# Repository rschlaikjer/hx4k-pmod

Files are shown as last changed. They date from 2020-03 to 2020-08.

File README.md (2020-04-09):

# HX4k PMOD Breakout

This repository contains the KiCad hardware design files, flash programming
firmware and some gateware samples for a basic FPGA breakout board based on the
Lattice Ice40 HX4K.

More information about this project can be found
[in this blog post](https://rhye.org/post/fpgas-1-running-on-hardware/).

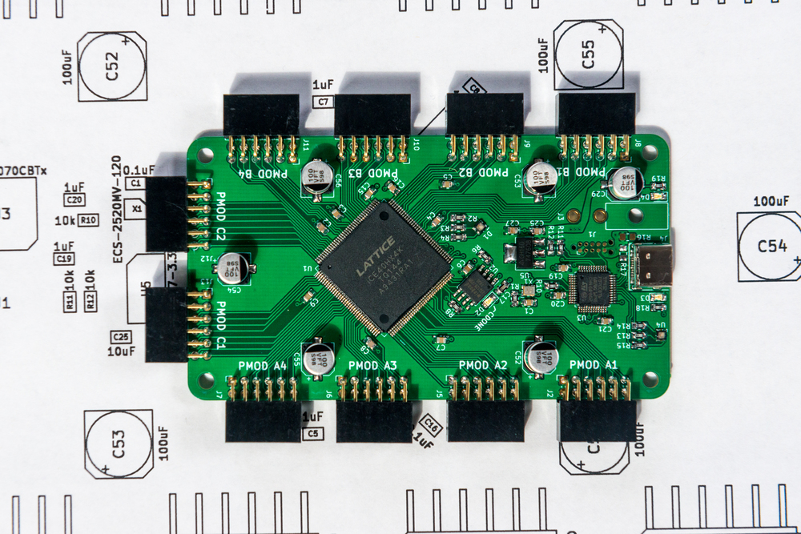
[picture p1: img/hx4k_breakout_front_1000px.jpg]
Assembled Board


## Building the hardware

### Prerequisites

- Soldering iron (TS-100 or TS-80 would be fine for this)
- Flux (Massively simplifies the soldering of the QFP packages)
- Fine tweezers (I recommend [Rhino SW-11](https://www.adafruit.com/product/3096) or comparable)
- [Optional] Hot air rework station. The '858D' hot air station is available
from many resellers at reasonable prices, and is more than adequate.

One of the design goals for this board was for it to be feasible to assemble by
hand, using only a soldering iron. To that end, all of the critical
components are leaded packages, and there are no passives smaller than 0805.
For some components (USB type-C connector J4, 12MHz oscillator X1 and RGB LEDs
D1 and U4), a hot air gun may be advantageous, but it is possible to get away
without one.

### Ordering PCBs

If you have done this before, you can clone this repo and then zip up the
gerber fills in the
[hardware/gerber/](https://github.com/rschlaikjer/hx4k-pmod/tree/master/hardware/gerber/)
directory and upload them to your preferred board house.
Alternately, or for convenience, you can
[order this design directly](https://www.pcbway.com/project/shareproject/Lattice_HX4K_FPGA_Breakout.html)
from PCBWay, a budget PCB house with respectable quality and turnaround time.

### Bill of materials

The KiCad design files are fully specified with the manufacturer and DigiKey
part numbers for all components involved. Also included in the `hardware/` folder
is a DigiKey BOM CSV (`digikey_bom.csv`), which can be uploaded
[here](https://www.digikey.com/BOM/) and used to immediately add the necessary
components to an order. Note that the BOM item quantity is for _precisely_ one
unit - I would recommend going through and adding whatever fudge factor you
feel is reasonable to cheaper passives and other parts you want some margin for
error with.

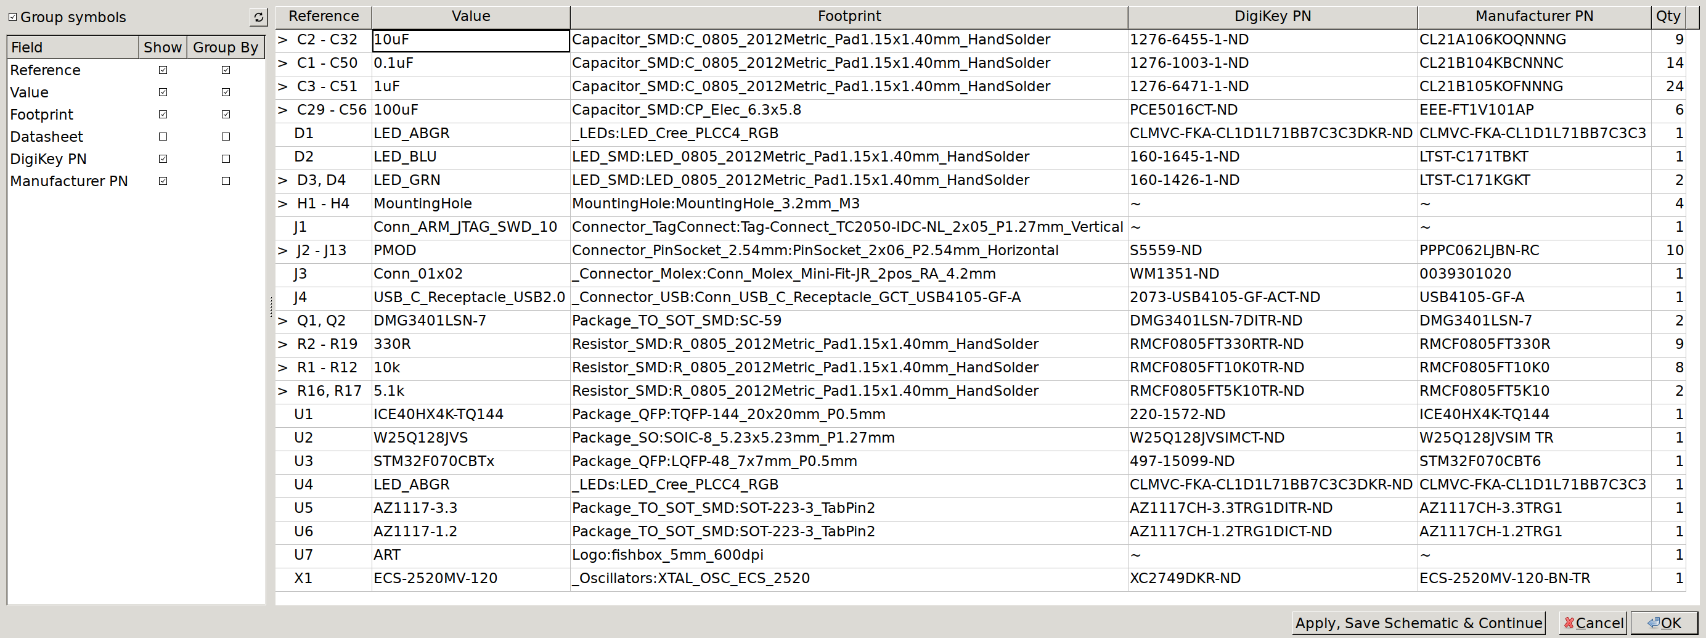
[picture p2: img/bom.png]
BOM View


At time of writing, the total cost of the BOM for no more than one board is $37.60.
If you intend to make more than one, the unit price will of course decrease.

### Assembly

I highly recommend printing out the `F.Fab` and `B.Fab` layers of the KiCad
design before getting to work, as these contain a wireframe layout of all the
components, as well as their associated values (pictured on right hand side). I
would also recommend starting with the center of the major component sections
(U1, U3) and working outwards to smaller components, otherwise some of the
decoupling caps near the chips may make it tricky to solder the QFPs.

If you are using a hot air station for assembly, I would recommend applying
flux to the pads, tinning them, placing the component on top and then using the
hot air tool to reflow it into place. I find 350°C to work well for leaded
solder. Be careful not to overheat the LEDs, as the plastic may melt.

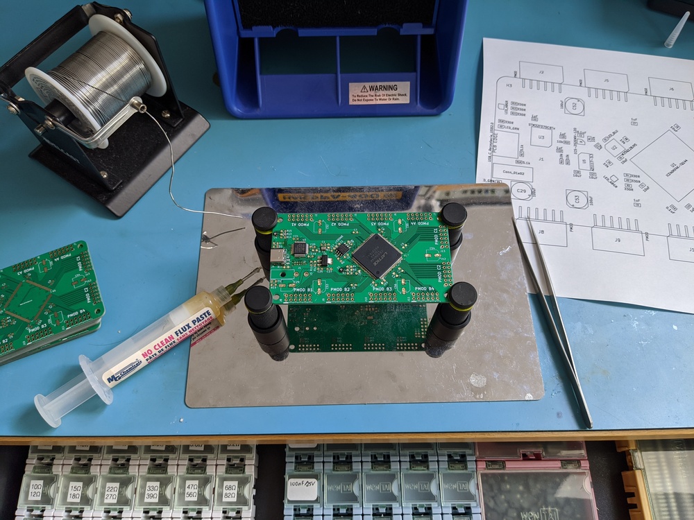
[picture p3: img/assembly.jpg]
Board Assembly


# Flashing the microcontroller

Once you have the hardware assembled, you will need to program the onboard
microcontroller. This micro then acts in much the same way as an FTDI FT2232
(but costs significantly less), and once set up allows for

- Writing bitstreams / other data to the onboard flash chip
- Creating a USB serial bridge to the FPGA
- Any other custom logic you want to add. The microcontroller has one hardware
SPI connected directly to the FPGA for end user applications.

To build the firmware, you will need the `arm-none-eabi` GCC toolchain:

    sudo apt install gcc-arm-none-eabi gdb-arm-none-eabi binutils-arm-none-eabi

You should then be able to build the firmware as a normal CMake project:

    # Ensure submodule for libopencm3 is present
    git submodule init
    git submodule update
    # Build
    mkdir programmer_firmware/build
    pushd programmer_firmware/build
    cmake ../
    make -j$(nproc)

To program, it is assumed that you will be using the
[Black Magic Probe](https://1bitsquared.com/products/black-magic-probe)
with a
[TagConnect TC-2050-NL](https://www.tag-connect.com/product/tc2050-idc-nl-050-all)
cable to connect to the programming pads on the board. In this case, after
connecting power to the board through either the USB connector or auxiliary
power connector,  you can
run the cmake target `fpga_programmer_flash` to attach to the microcontroller
and load the firmware. You should see output like the following:

    ross@mjolnir:/h/r/P/G/f/p/build$ make fpga_programmer_flash
    [ 44%] Built target libopencm3
    [100%] Built target fpga_programmer_elf
    Black Magic Probe (Firmware v1.6.1-311-gfbf1963) (Hardware Version 3)

    Available Targets:
    No. Att Driver
     1      STM32F07 M0
    event_loop () at /home/ross/Programming/Github/fpga-swe-1/programmer_firmware/src/main.cpp:87
    87	}
    Loading section .text, size 0x29e4 lma 0x8000000
    Loading section .init_array, size 0x8 lma 0x80029e4
    Loading section .data, size 0x14 lma 0x80029ec
    Start address 0x8001e84, load size 10752
    Transfer rate: 18 KB/sec, 768 bytes/write.
    Section .text, range 0x8000000 -- 0x80029e4: matched.
    Section .init_array, range 0x80029e4 -- 0x80029ec: matched.
    Section .data, range 0x80029ec -- 0x8002a00: matched.
    Kill the program being debugged? (y or n) [answered Y; input not from terminal]
    [100%] Built target fpga_programmer_flash

You should then see the board show up as a USB device, with the default VID:PID
set to a generic test PID:

    ross@mjolnir:/h/r/P/G/f/p/build$ lsusb -d 1209:0001
    Bus 001 Device 106: ID 1209:0001 Generic pid.codes Test PID

You should also notice that it has supplied a new serial device. This serial
port controls the hardware UART on the microcontroller, which is connected
directly to two pins on the FPGA and by default expects a baudrate of 2M.

## Flashing the FPGA

In order to generate bitstreams for the FPGA, you will first need to install
[yosys](https://github.com/YosysHQ/yosys),
[icestorm](http://www.clifford.at/icestorm/)
and
[nextpnr](https://github.com/YosysHQ/nextpnr). Instructions for all of them are
on their respective homepages.

Once these are installed, if you run `make` in the `gateware/` subfolder you
should be able to generate a `top.bin` bitstream of the demo application, which
will blink some lights and act as an echo UART.

In order to upload the bitstream, you will then need to build
[faff](https://github.com/rschlaikjer/faff),
a tool that handles the USB communication necessary to erase and reprogram the
flash through the microcontroller.

Once you have that installed and in your `$PATH`, you can run `make prog` from
the `gateware/` directory and should see it connect and program successfully:

    ross@mjolnir:/h/r/P/G/f/gateware$ make prog
    faff -f top.bin
    Claimed device 1209:0001 with serial 004700254753511120303234
    Flash chip mfgr: 0xef, Device ID: 0x17 Unique ID: 0xe4682c404b163333
    Programming block 0x00020fa0 / 0x00020fbc
    Reading block 0x00020fa0 / 0x00020fbc

Your FPGA should now cycle through some various colours on the RGB LED.

Blink Demo

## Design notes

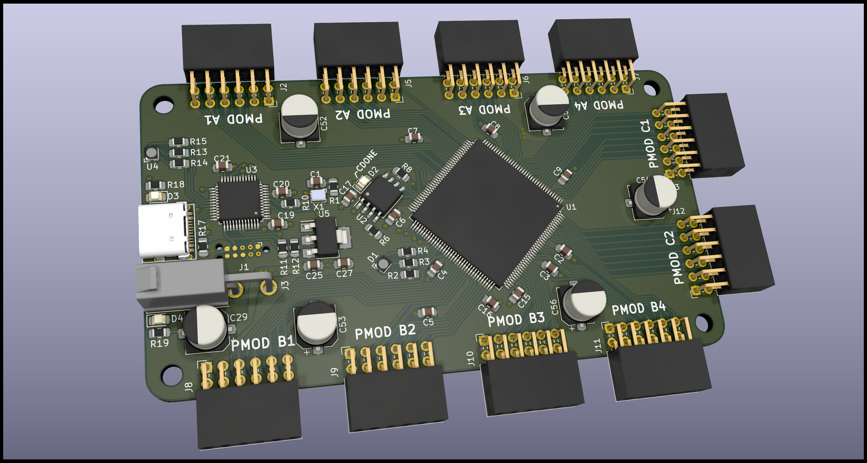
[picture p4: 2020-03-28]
hardware/front.png

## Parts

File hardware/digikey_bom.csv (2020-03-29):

Manufacturer Part Number | Manufacturer | Digi-Key Part Number | Customer Reference | Reference Designator | Packaging | Part Status | Quantity | Unit Price | Extended Price | Quantity Available | Mfg Std Lead Time | Description | RoHS Status | Lead Free Status | REACH Status
CL21A106KOQNNNG | Samsung Electro-Mechanics | 1276-6455-1-ND | Capacitor, 10uF |  | Cut Tape (CT) | Active | 9 | 0.13000 | $1.17 | 51329 | 22 Weeks | CAP CER 10UF 16V X5R 0805 | ROHS3 Compliant | Lead free | REACH Unaffected
CL21B104KBCNNNC | Samsung Electro-Mechanics | 1276-1003-1-ND | Capacitor, 0.1uF |  | Cut Tape (CT) | Active | 14 | 0.05400 | $0.75 | 3598 | 22 Weeks | CAP CER 0.1UF 50V X7R 0805 | ROHS3 Compliant | Lead free | REACH Unaffected
CL21B105KOFNNNG | Samsung Electro-Mechanics | 1276-6471-1-ND | Capacitor, 1uF |  | Cut Tape (CT) | Active | 25 | 0.06300 | $1.57 | 84780 | 22 Weeks | CAP CER 1UF 16V X7R 0805 | ROHS3 Compliant | Lead free | REACH Unaffected
EEE-FT1V101AP | Panasonic Electronic Components | PCE5016CT-ND | Capacitor, 100uF |  | Cut Tape (CT) | Active | 6 | 0.56000 | $3.36 | 141712 | 17 Weeks | CAP ALUM 100UF 20% 35V SMD | RoHS Compliant | Lead free | Not Available
LTST-C171TBKT | Lite-On Inc. | 160-1645-1-ND | LED, Blue |  | Cut Tape (CT) | Active | 1 | 0.46000 | $0.46 | 129189 | 12 Weeks | LED BLUE CLEAR CHIP SMD | ROHS3 Compliant | Lead free | Not Available
LTST-C171KGKT | Lite-On Inc. | 160-1426-1-ND | LED, Green |  | Cut Tape (CT) | Active | 2 | 0.28000 | $0.56 | 108682 | 12 Weeks | LED GREEN CLEAR SMD | ROHS3 Compliant | Lead free | Not Available
PPPC062LJBN-RC | Sullins Connector Solutions | S5559-ND | PMOD Header |  | Tray | Active | 10 | 1.11500 | $11.15 | 9973 | 5 Weeks | CONN HDR 12POS 0.1 GOLD PCB R/A | ROHS3 Compliant | Lead free | REACH Unaffected
0039301020 | Molex | WM1351-ND | Power connector |  | Bulk | Active | 3 | 0.57000 | $1.71 | 12848 | 5 Weeks | CONN HEADER R/A 2POS | ROHS3 Compliant | Lead free | REACH Unaffected
USB4105-GF-A | GCT | 2073-USB4105-GF-ACT-ND | USB Type-C Connector |  | Cut Tape (CT) | Active | 1 | 1.73000 | $1.73 | 509 | 7 Weeks | CONN RCPT USB2.0 TYPEC 5A | ROHS3 Compliant | Not Available | Not Available
DMG3401LSN-7 | Diodes Incorporated | DMG3401LSN-7DICT-ND | Reverse-voltage protection FETs |  | Cut Tape (CT) | Active | 2 | 0.48000 | $0.96 | 121857 | 15 Weeks | MOSFET P-CH 30V 3A SC59 | ROHS3 Compliant | Lead free | REACH Unaffected
RMCF0805FT330R | Stackpole Electronics Inc | RMCF0805FT330RCT-ND | Resistor, 330R |  | Cut Tape (CT) | Active | 9 | 0.10000 | $0.90 | 120483 | 20 Weeks | RES 330 OHM 1% 1/8W 0805 | ROHS3 Compliant | Lead free | REACH Unaffected
RMCF0805FT10K0 | Stackpole Electronics Inc | RMCF0805FT10K0CT-ND | Resistor, 10K |  | Cut Tape (CT) | Active | 8 | 0.10000 | $0.80 | 1844634 | 20 Weeks | RES 10K OHM 1% 1/8W 0805 | ROHS3 Compliant | Lead free | REACH Unaffected
RMCF0805FT5K10 | Stackpole Electronics Inc | RMCF0805FT5K10CT-ND | Resistor, 5.1K |  | Cut Tape (CT) | Active | 2 | 0.10000 | $0.20 | 53396 | 20 Weeks | RES 5.1K OHM 1% 1/8W 0805 | ROHS3 Compliant | Lead free | REACH Unaffected
ICE40HX4K-TQ144 | Lattice Semiconductor Corporation | 220-1572-ND | HX4K FPGA |  | Tray | Active | 1 | 6.31000 | $6.31 | 441 | 8 Weeks | IC FPGA 107 I/O 144TQFP | ROHS3 Compliant | Lead free | REACH Unaffected
W25Q128JVSIM | Winbond Electronics | W25Q128JVSIM-ND | Bitstream flash |  | Tube | Active | 1 | 1.40000 | $1.40 | 0 | 10 Weeks | IC FLASH 128M SPI 133MHZ 8SOIC | ROHS3 Compliant | Lead free | REACH Unaffected
STM32F070CBT6 | STMicroelectronics | 497-15099-ND | Interface MCU |  | Tray | Active | 1 | 2.38000 | $2.38 | 1860 | 10 Weeks | IC MCU 32BIT 128KB FLASH 48LQFP | ROHS3 Compliant | Lead free | REACH Unaffected
CLMVC-FKA-CL1D1L71BB7C3C3 | Cree Inc. | CLMVC-FKA-CL1D1L71BB7C3C3CT-ND | RGB LED |  | Cut Tape (CT) | Active | 2 | 0.19000 | $0.38 | 43616 | 7 Weeks | LED RGB CLEAR 4PLCC SMD | RoHS Compliant | Lead free | Not Available
AZ1117CH-3.3TRG1 | Diodes Incorporated | AZ1117CH-3.3TRG1DICT-ND | 3.3V LDO |  | Cut Tape (CT) | Active | 1 | 0.43000 | $0.43 | 24536 | 11 Weeks | IC REG LINEAR 3.3V 800MA SOT223 | ROHS3 Compliant | Lead free | REACH Unaffected
AZ1117CH-1.2TRG1 | Diodes Incorporated | AZ1117CH-1.2TRG1DICT-ND | 1.2V LDO (FPGA Core) |  | Cut Tape (CT) | Active | 1 | 0.38000 | $0.38 | 5022 | 24 Weeks | IC REG LINEAR 1.2V 800MA SOT223 | ROHS3 Compliant | Lead free | REACH Unaffected
ECS-2520MV-120-BN-TR | ECS Inc. | XC2749CT-ND | 12 MHz Oscillator |  | Cut Tape (CT) | Active | 1 | 1.00000 | $1.00 | 3652 | 13 Weeks | XTAL OSC XO 12.0000MHZ CMOS SMD | ROHS3 Compliant | Lead free | Not Available

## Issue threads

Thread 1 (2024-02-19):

The firmware process ends with an error

Yarulik, 2024-02-19:
Good day!
Sorry for the stupid questions! This is my first FPGA and I'm just starting this journey.
I followed your tutorial, but flashed the STM using ST-LINK.
I was able to build a binary file after changing .blink/Makefile
ARGS := -abc9, changed to -abc and then it compiled.
But when flashing the blink firmware in the FPGA, an error appears:

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

> Expected:    FF 00 00 FF 77 AA 99 77 55 00 00 00 99 00 22 66 00 66 77 00 11 88 00 00 11 00 00 00 00 00 00 00

>

> Read:   00 00 00 00 00 00 00 00 00 00 00 00 00 00 00 00 00 00 00 00 00 00 00 00 00 00 00 00 00 00 00 00`

The memory chip is working!
What did I do wrong?
Maybe I didn't compile one of the binaries correctly?

rschlaikjer, 2024-02-19:
Hmm, that looks to me something wrong with the connection to the flash chip - (almost) all zeroes for the unique ID fields? Is it definitely a compatible part / soldered correctly? Do you have a logic analyzer that you can scope the data pins with? Also possible that if the reset line from the stm32 to the fpga isn't working the fpga is still asserting some of the SPI pins in confluct with the stm32.

> The memory chip is working!

How did you verify this?

Yarulik, 2024-02-19:
I have two memory chips. Okay, I'll check with a logic analyzer

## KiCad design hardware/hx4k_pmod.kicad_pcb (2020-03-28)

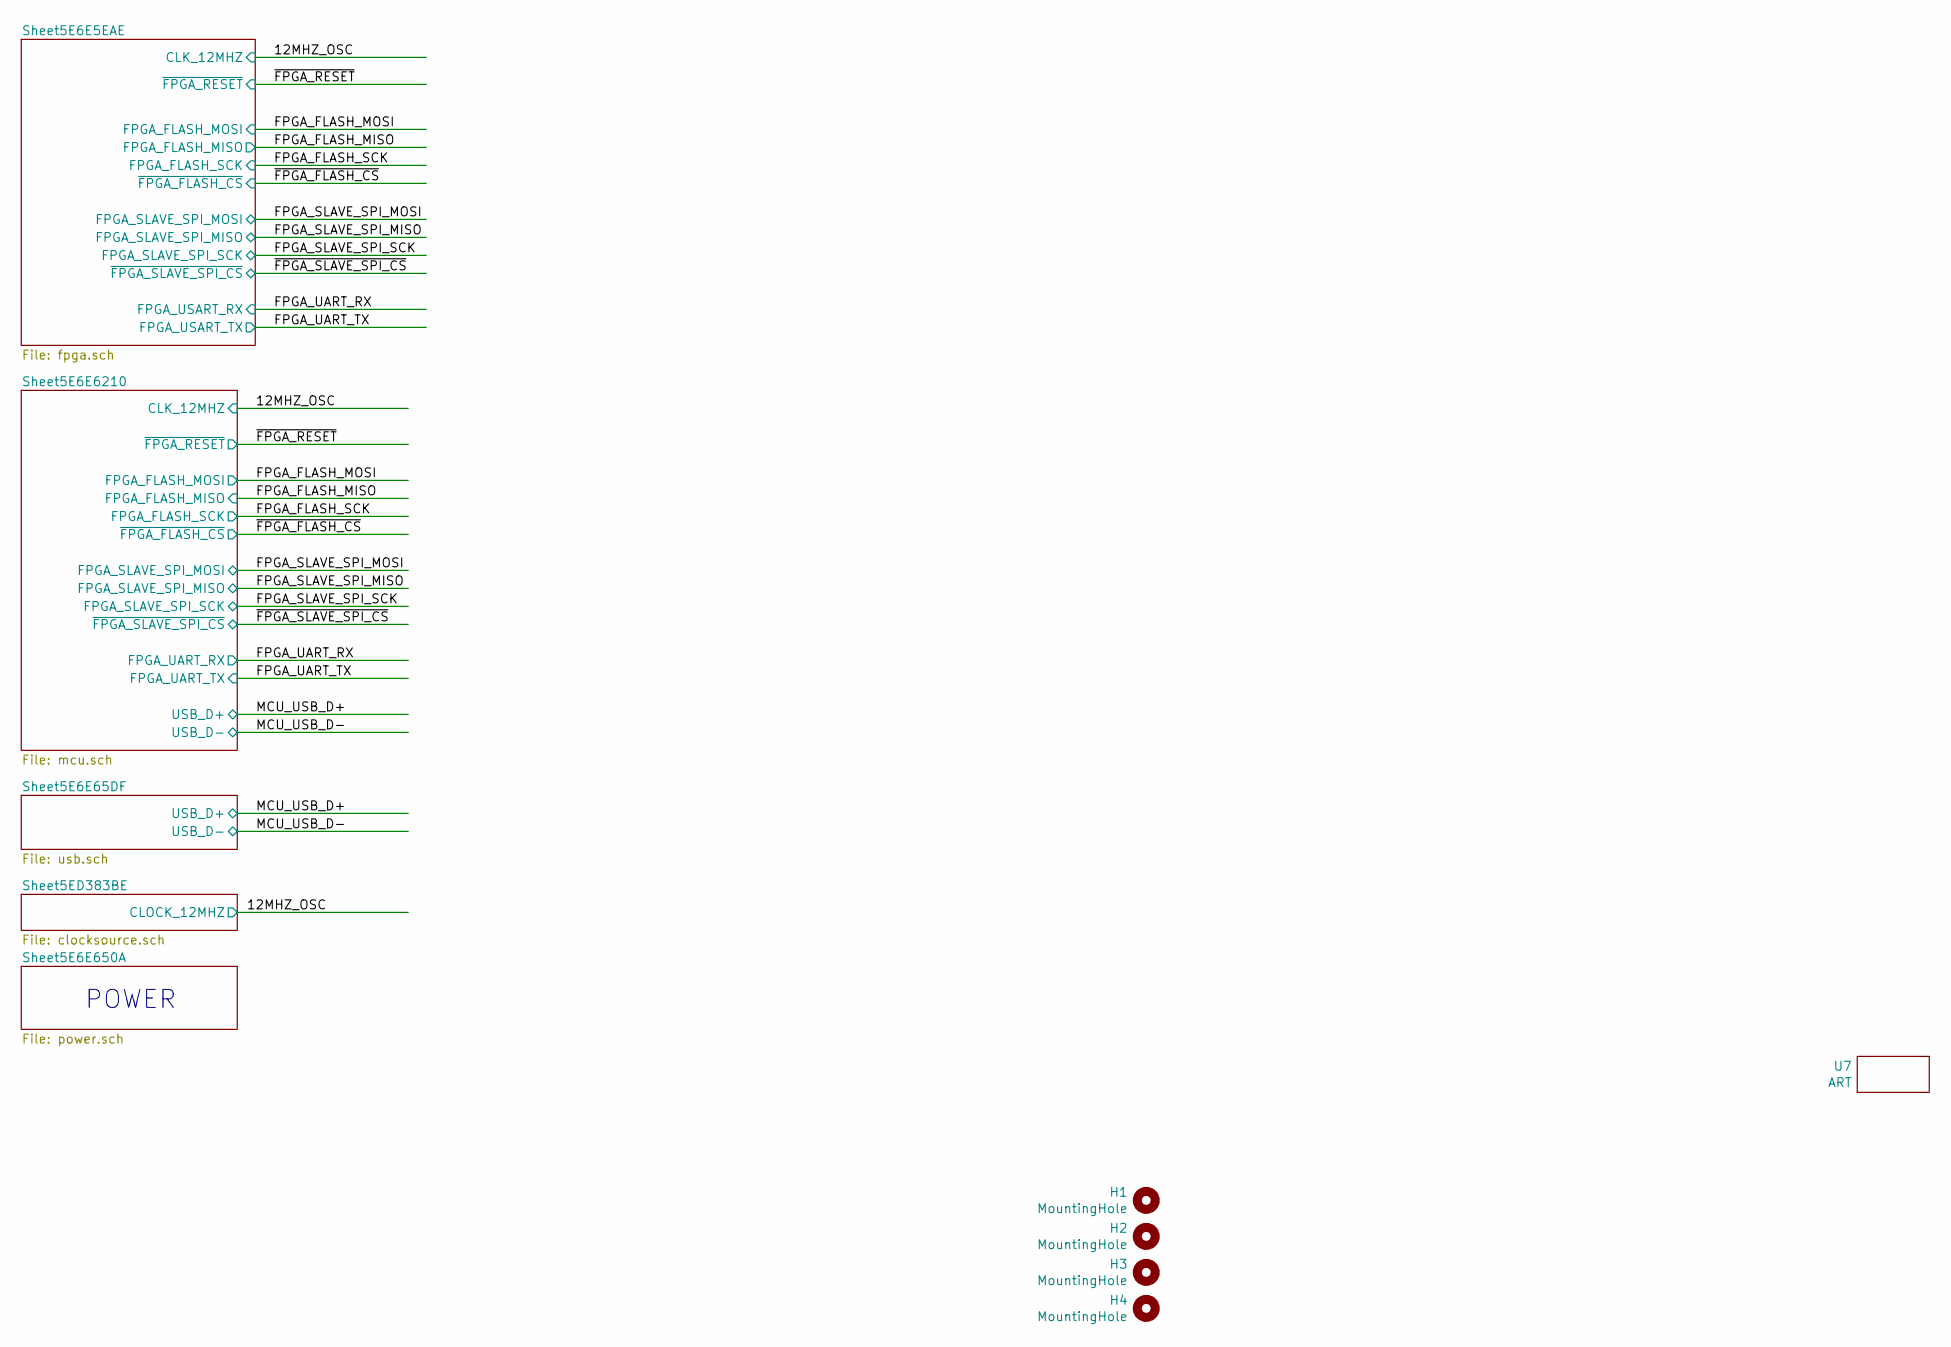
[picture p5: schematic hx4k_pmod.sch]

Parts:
H1, H2, H3, H4: MountingHole; MountingHole_3.2mm_M3
U7: ART; fishbox_5mm_600dpi

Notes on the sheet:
POWER

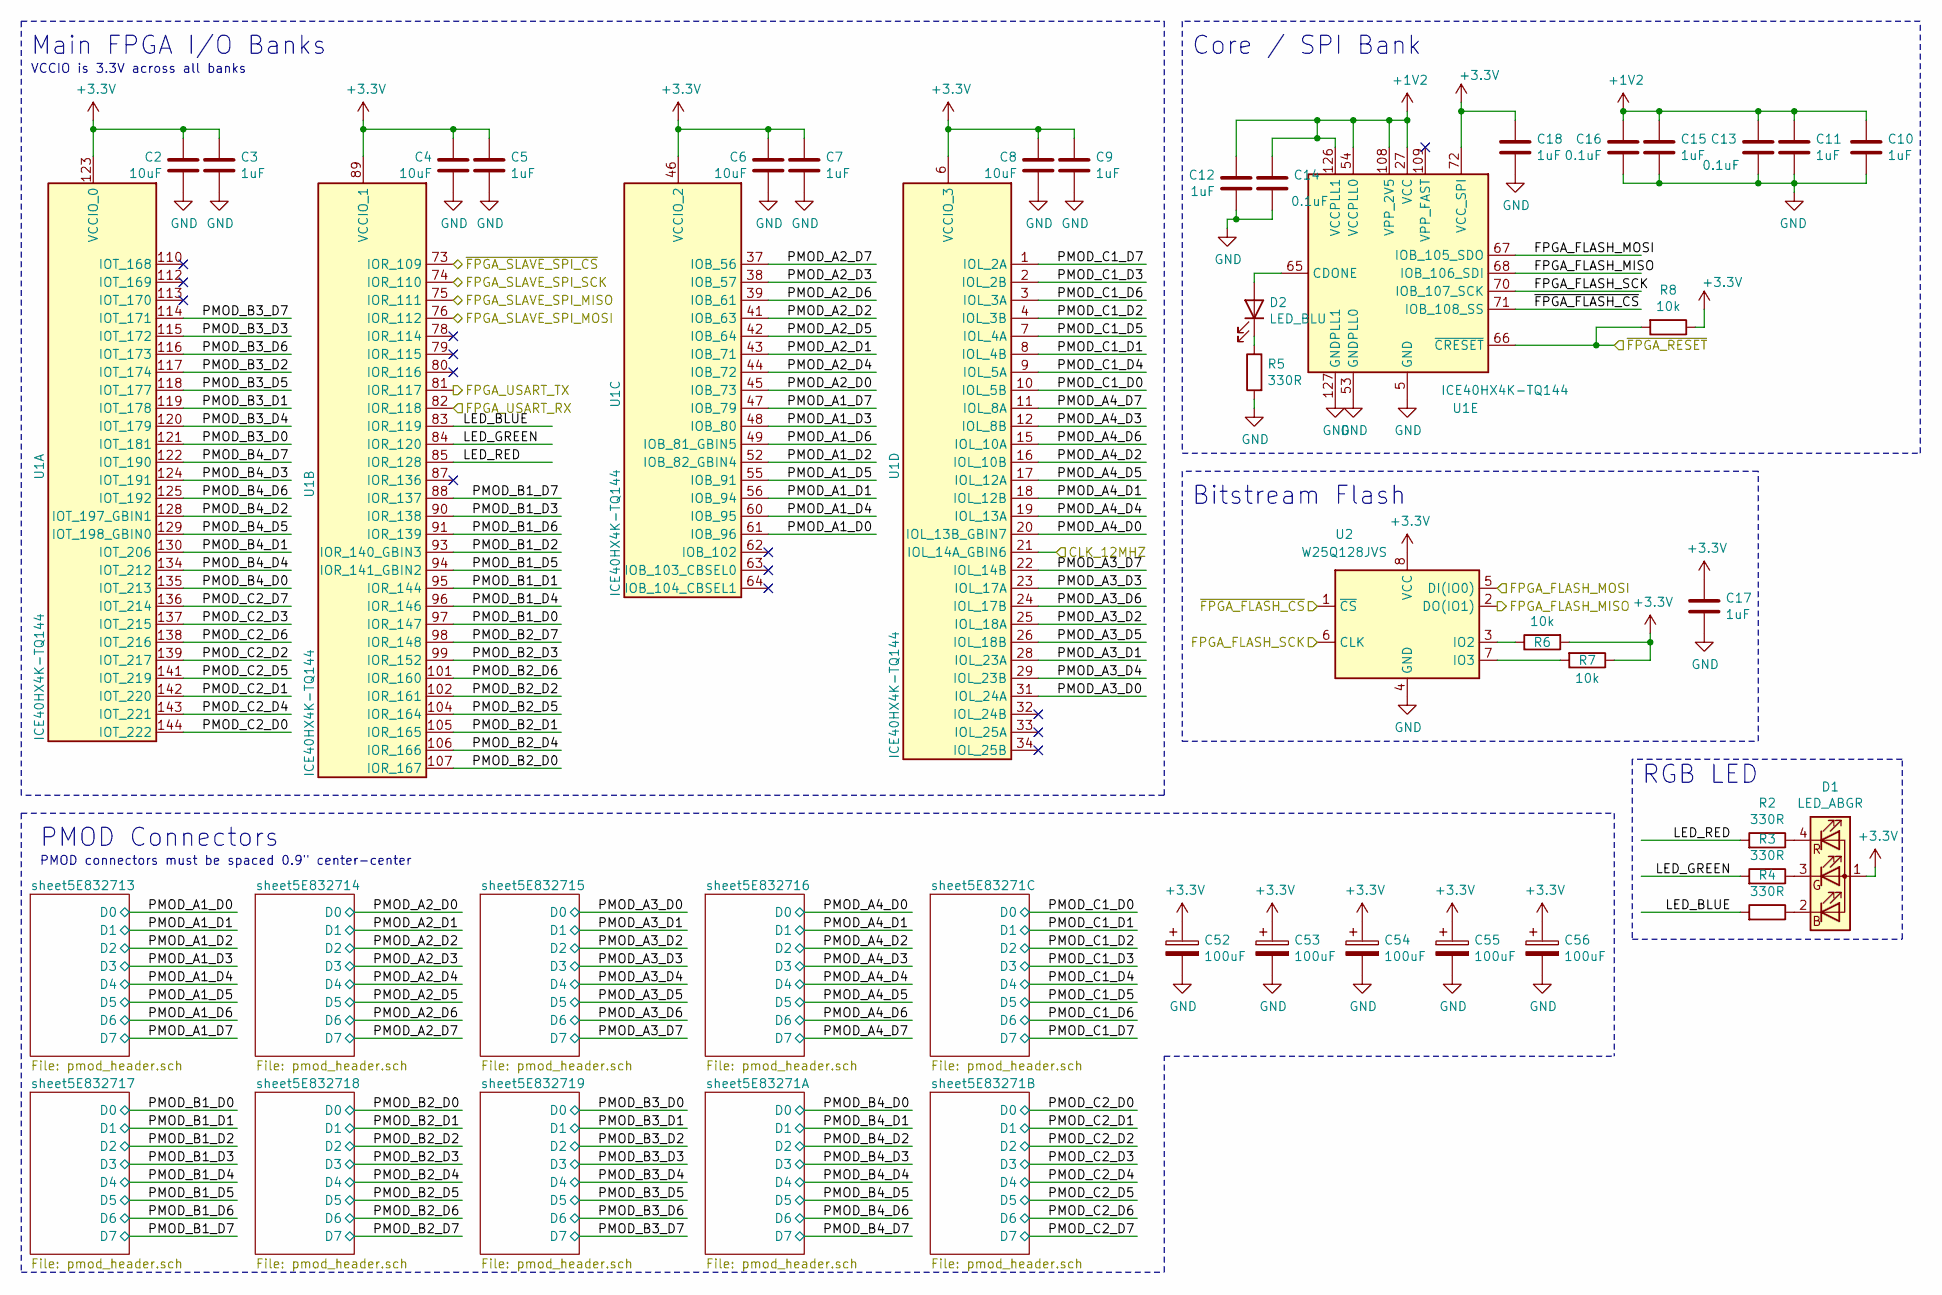
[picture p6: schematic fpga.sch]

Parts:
C2, C4, C6, C8: 10uF; C_0805_2012Metric_Pad1.15x1.40mm_HandSolder; Manufacturer PN CL21A106KOQNNNG; DigiKey PN 1276-6455-1-ND
C3, C5, C7, C9, C10, C11, C12, C15, C17, C18: 1uF; C_0805_2012Metric_Pad1.15x1.40mm_HandSolder; Manufacturer PN CL21B105KOFNNNG; DigiKey PN 1276-6471-1-ND
C13, C14, C16: 0.1uF; C_0805_2012Metric_Pad1.15x1.40mm_HandSolder; Manufacturer PN CL21B104KBCNNNC; DigiKey PN 1276-1003-1-ND
C52, C53, C54, C55, C56: 100uF; CP_Elec_6.3x5.8; Manufacturer PN EEE-FT1V101AP; DigiKey PN PCE5016CT-ND
D1: LED_ABGR; LED_Cree_PLCC4_RGB; Manufacturer PN CLMVC-FKA-CL1D1L71BB7C3C3; DigiKey PN CLMVC-FKA-CL1D1L71BB7C3C3DKR-ND
D2: LED_BLU; LED_0805_2012Metric_Pad1.15x1.40mm_HandSolder; Manufacturer PN LTST-C171TBKT; DigiKey PN 160-1645-1-ND
R2, R3, R4, R5: 330R; R_0805_2012Metric_Pad1.15x1.40mm_HandSolder; Manufacturer PN RMCF0805FT330R; DigiKey PN RMCF0805FT330RTR-ND
R6, R7, R8: 10k; R_0805_2012Metric_Pad1.15x1.40mm_HandSolder; Manufacturer PN RMCF0805FT10K0; DigiKey PN RMCF0805FT10K0TR-ND
U1: ICE40HX4K-TQ144; TQFP-144_20x20mm_P0.5mm; Manufacturer PN ICE40HX4K-TQ144; DigiKey PN 220-1572-ND
U2: W25Q128JVS; SOIC-8_5.23x5.23mm_P1.27mm; Manufacturer PN W25Q128JVSIM TR; DigiKey PN W25Q128JVSIMCT-ND

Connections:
+1V2: C10.2, C11.2, C12.2, C13.2, C14.2, C15.2, C16.1, U1.27 (VCC), U1.40 (VCC), U1.54 (VCCPLL0), U1.92 (VCC), U1.108 (VPP_2V5), U1.111 (VCC), U1.126 (VCCPLL1); also elsewhere on the board
/12MHZ_OSC: U1.21 (IOL_14A_GBIN6); also elsewhere on the board
/FPGA_FLASH_MISO: U1.68 (IOB_106_SDI), U2.2 (DO(IO1)); also elsewhere on the board
/FPGA_FLASH_MOSI: U1.67 (IOB_105_SDO), U2.5 (DI(IO0)); also elsewhere on the board
/FPGA_FLASH_SCK: U1.70 (IOB_107_SCK), U2.6 (CLK); also elsewhere on the board
/FPGA_SLAVE_SPI_MISO: U1.75 (IOR_111); also elsewhere on the board
/FPGA_SLAVE_SPI_MOSI: U1.76 (IOR_112); also elsewhere on the board
/FPGA_SLAVE_SPI_SCK: U1.74 (IOR_110); also elsewhere on the board
/FPGA_UART_RX: U1.82 (IOR_118); also elsewhere on the board
/FPGA_UART_TX: U1.81 (IOR_117); also elsewhere on the board
/Sheet5E6E5EAE/LED_BLUE: R4.2, U1.83 (IOR_119)
/Sheet5E6E5EAE/LED_GREEN: R3.2, U1.84 (IOR_120)
/Sheet5E6E5EAE/LED_RED: R2.2, U1.85 (IOR_128)
/Sheet5E6E5EAE/PMOD_A1_D0: U1.61 (IOB_96); also elsewhere on the board
/Sheet5E6E5EAE/PMOD_A1_D1: U1.56 (IOB_94); also elsewhere on the board
/Sheet5E6E5EAE/PMOD_A1_D2: U1.52 (IOB_82_GBIN4); also elsewhere on the board
/Sheet5E6E5EAE/PMOD_A1_D3: U1.48 (IOB_80); also elsewhere on the board
/Sheet5E6E5EAE/PMOD_A1_D4: U1.60 (IOB_95); also elsewhere on the board
/Sheet5E6E5EAE/PMOD_A1_D5: U1.55 (IOB_91); also elsewhere on the board
/Sheet5E6E5EAE/PMOD_A1_D6: U1.49 (IOB_81_GBIN5); also elsewhere on the board
/Sheet5E6E5EAE/PMOD_A1_D7: U1.47 (IOB_79); also elsewhere on the board
/Sheet5E6E5EAE/PMOD_A2_D0: U1.45 (IOB_73); also elsewhere on the board
/Sheet5E6E5EAE/PMOD_A2_D1: U1.43 (IOB_71); also elsewhere on the board
/Sheet5E6E5EAE/PMOD_A2_D2: U1.41 (IOB_63); also elsewhere on the board
/Sheet5E6E5EAE/PMOD_A2_D3: U1.38 (IOB_57); also elsewhere on the board
/Sheet5E6E5EAE/PMOD_A2_D4: U1.44 (IOB_72); also elsewhere on the board
/Sheet5E6E5EAE/PMOD_A2_D5: U1.42 (IOB_64); also elsewhere on the board
/Sheet5E6E5EAE/PMOD_A2_D6: U1.39 (IOB_61); also elsewhere on the board
/Sheet5E6E5EAE/PMOD_A2_D7: U1.37 (IOB_56); also elsewhere on the board
/Sheet5E6E5EAE/PMOD_A3_D0: U1.31 (IOL_24A); also elsewhere on the board
/Sheet5E6E5EAE/PMOD_A3_D1: U1.28 (IOL_23A); also elsewhere on the board
/Sheet5E6E5EAE/PMOD_A3_D2: U1.25 (IOL_18A); also elsewhere on the board
/Sheet5E6E5EAE/PMOD_A3_D3: U1.23 (IOL_17A); also elsewhere on the board
/Sheet5E6E5EAE/PMOD_A3_D4: U1.29 (IOL_23B); also elsewhere on the board
/Sheet5E6E5EAE/PMOD_A3_D5: U1.26 (IOL_18B); also elsewhere on the board
/Sheet5E6E5EAE/PMOD_A3_D6: U1.24 (IOL_17B); also elsewhere on the board
/Sheet5E6E5EAE/PMOD_A3_D7: U1.22 (IOL_14B); also elsewhere on the board
/Sheet5E6E5EAE/PMOD_A4_D0: U1.20 (IOL_13B_GBIN7); also elsewhere on the board
/Sheet5E6E5EAE/PMOD_A4_D1: U1.18 (IOL_12B); also elsewhere on the board
/Sheet5E6E5EAE/PMOD_A4_D2: U1.16 (IOL_10B); also elsewhere on the board
/Sheet5E6E5EAE/PMOD_A4_D3: U1.12 (IOL_8B); also elsewhere on the board
/Sheet5E6E5EAE/PMOD_A4_D4: U1.19 (IOL_13A); also elsewhere on the board
/Sheet5E6E5EAE/PMOD_A4_D5: U1.17 (IOL_12A); also elsewhere on the board
/Sheet5E6E5EAE/PMOD_A4_D6: U1.15 (IOL_10A); also elsewhere on the board
/Sheet5E6E5EAE/PMOD_A4_D7: U1.11 (IOL_8A); also elsewhere on the board
/Sheet5E6E5EAE/PMOD_B1_D0: U1.97 (IOR_147); also elsewhere on the board
/Sheet5E6E5EAE/PMOD_B1_D1: U1.95 (IOR_144); also elsewhere on the board
/Sheet5E6E5EAE/PMOD_B1_D2: U1.93 (IOR_140_GBIN3); also elsewhere on the board
/Sheet5E6E5EAE/PMOD_B1_D3: U1.90 (IOR_138); also elsewhere on the board
/Sheet5E6E5EAE/PMOD_B1_D4: U1.96 (IOR_146); also elsewhere on the board
/Sheet5E6E5EAE/PMOD_B1_D5: U1.94 (IOR_141_GBIN2); also elsewhere on the board
/Sheet5E6E5EAE/PMOD_B1_D6: U1.91 (IOR_139); also elsewhere on the board
/Sheet5E6E5EAE/PMOD_B1_D7: U1.88 (IOR_137); also elsewhere on the board
/Sheet5E6E5EAE/PMOD_B2_D0: U1.107 (IOR_167); also elsewhere on the board
/Sheet5E6E5EAE/PMOD_B2_D1: U1.105 (IOR_165); also elsewhere on the board
/Sheet5E6E5EAE/PMOD_B2_D2: U1.102 (IOR_161); also elsewhere on the board
/Sheet5E6E5EAE/PMOD_B2_D3: U1.99 (IOR_152); also elsewhere on the board
/Sheet5E6E5EAE/PMOD_B2_D4: U1.106 (IOR_166); also elsewhere on the board
/Sheet5E6E5EAE/PMOD_B2_D5: U1.104 (IOR_164); also elsewhere on the board
/Sheet5E6E5EAE/PMOD_B2_D6: U1.101 (IOR_160); also elsewhere on the board
/Sheet5E6E5EAE/PMOD_B2_D7: U1.98 (IOR_148); also elsewhere on the board
/Sheet5E6E5EAE/PMOD_B3_D0: U1.121 (IOT_181); also elsewhere on the board
/Sheet5E6E5EAE/PMOD_B3_D1: U1.119 (IOT_178); also elsewhere on the board
/Sheet5E6E5EAE/PMOD_B3_D2: U1.117 (IOT_174); also elsewhere on the board
/Sheet5E6E5EAE/PMOD_B3_D3: U1.115 (IOT_172); also elsewhere on the board
/Sheet5E6E5EAE/PMOD_B3_D4: U1.120 (IOT_179); also elsewhere on the board
/Sheet5E6E5EAE/PMOD_B3_D5: U1.118 (IOT_177); also elsewhere on the board
/Sheet5E6E5EAE/PMOD_B3_D6: U1.116 (IOT_173); also elsewhere on the board
/Sheet5E6E5EAE/PMOD_B3_D7: U1.114 (IOT_171); also elsewhere on the board
/Sheet5E6E5EAE/PMOD_B4_D0: U1.135 (IOT_213); also elsewhere on the board
/Sheet5E6E5EAE/PMOD_B4_D1: U1.130 (IOT_206); also elsewhere on the board
/Sheet5E6E5EAE/PMOD_B4_D2: U1.128 (IOT_197_GBIN1); also elsewhere on the board
/Sheet5E6E5EAE/PMOD_B4_D3: U1.124 (IOT_191); also elsewhere on the board
/Sheet5E6E5EAE/PMOD_B4_D4: U1.134 (IOT_212); also elsewhere on the board
/Sheet5E6E5EAE/PMOD_B4_D5: U1.129 (IOT_198_GBIN0); also elsewhere on the board
/Sheet5E6E5EAE/PMOD_B4_D6: U1.125 (IOT_192); also elsewhere on the board
/Sheet5E6E5EAE/PMOD_B4_D7: U1.122 (IOT_190); also elsewhere on the board
/Sheet5E6E5EAE/PMOD_C1_D0: U1.10 (IOL_5B); also elsewhere on the board
/Sheet5E6E5EAE/PMOD_C1_D1: U1.8 (IOL_4B); also elsewhere on the board
/Sheet5E6E5EAE/PMOD_C1_D2: U1.4 (IOL_3B); also elsewhere on the board
/Sheet5E6E5EAE/PMOD_C1_D3: U1.2 (IOL_2B); also elsewhere on the board
/Sheet5E6E5EAE/PMOD_C1_D4: U1.9 (IOL_5A); also elsewhere on the board
/Sheet5E6E5EAE/PMOD_C1_D5: U1.7 (IOL_4A); also elsewhere on the board
/Sheet5E6E5EAE/PMOD_C1_D6: U1.3 (IOL_3A); also elsewhere on the board
/Sheet5E6E5EAE/PMOD_C1_D7: U1.1 (IOL_2A); also elsewhere on the board
/Sheet5E6E5EAE/PMOD_C2_D0: U1.144 (IOT_222); also elsewhere on the board
/Sheet5E6E5EAE/PMOD_C2_D1: U1.142 (IOT_220); also elsewhere on the board
/Sheet5E6E5EAE/PMOD_C2_D2: U1.139 (IOT_217); also elsewhere on the board
/Sheet5E6E5EAE/PMOD_C2_D3: U1.137 (IOT_215); also elsewhere on the board
/Sheet5E6E5EAE/PMOD_C2_D4: U1.143 (IOT_221); also elsewhere on the board
/Sheet5E6E5EAE/PMOD_C2_D5: U1.141 (IOT_219); also elsewhere on the board
/Sheet5E6E5EAE/PMOD_C2_D6: U1.138 (IOT_216); also elsewhere on the board
/Sheet5E6E5EAE/PMOD_C2_D7: U1.136 (IOT_214); also elsewhere on the board
/~FPGA_FLASH_CS: U1.71 (IOB_108_SS), U2.1 (~CS); also elsewhere on the board
/~FPGA_RESET: R8.2, U1.66 (~CRESET); also elsewhere on the board
/~FPGA_SLAVE_SPI_CS: U1.73 (IOR_109); also elsewhere on the board
GND: C2.1, C3.2, C4.1, C5.2, C6.1, C7.2, C8.1, C9.2, C10.1, C11.1, C12.1, C13.1, C14.1, C15.1, C16.2, C17.2, C18.2, C52.2, C53.2, C54.2, C55.2, C56.2, R5.2, U1.5 (GND), U1.13 (GND), U1.14 (GND), U1.53 (GNDPLL0), U1.59 (GND), U1.69 (GND), U1.86 (GND), U1.103 (GND), U1.127 (GNDPLL1), U1.132 (GND), U1.140 (GND), U2.4 (GND); also elsewhere on the board
unnamed: D1.2 (BK), R4.1
unnamed: D1.3 (GK), R3.1
unnamed: D1.4 (RK), R2.1
unnamed: D2.1 (K), R5.1
unnamed: D2.2 (A), U1.65 (CDONE)
unnamed: R6.1, U2.3 (IO2)
unnamed: R7.2, U2.7 (IO3)

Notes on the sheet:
PMOD connectors must be spaced 0.9" center-center
RGB LED
Bitstream Flash
Core / SPI Bank
PMOD Connectors
Main FPGA I/O Banks
VCCIO is 3.3V across all banks

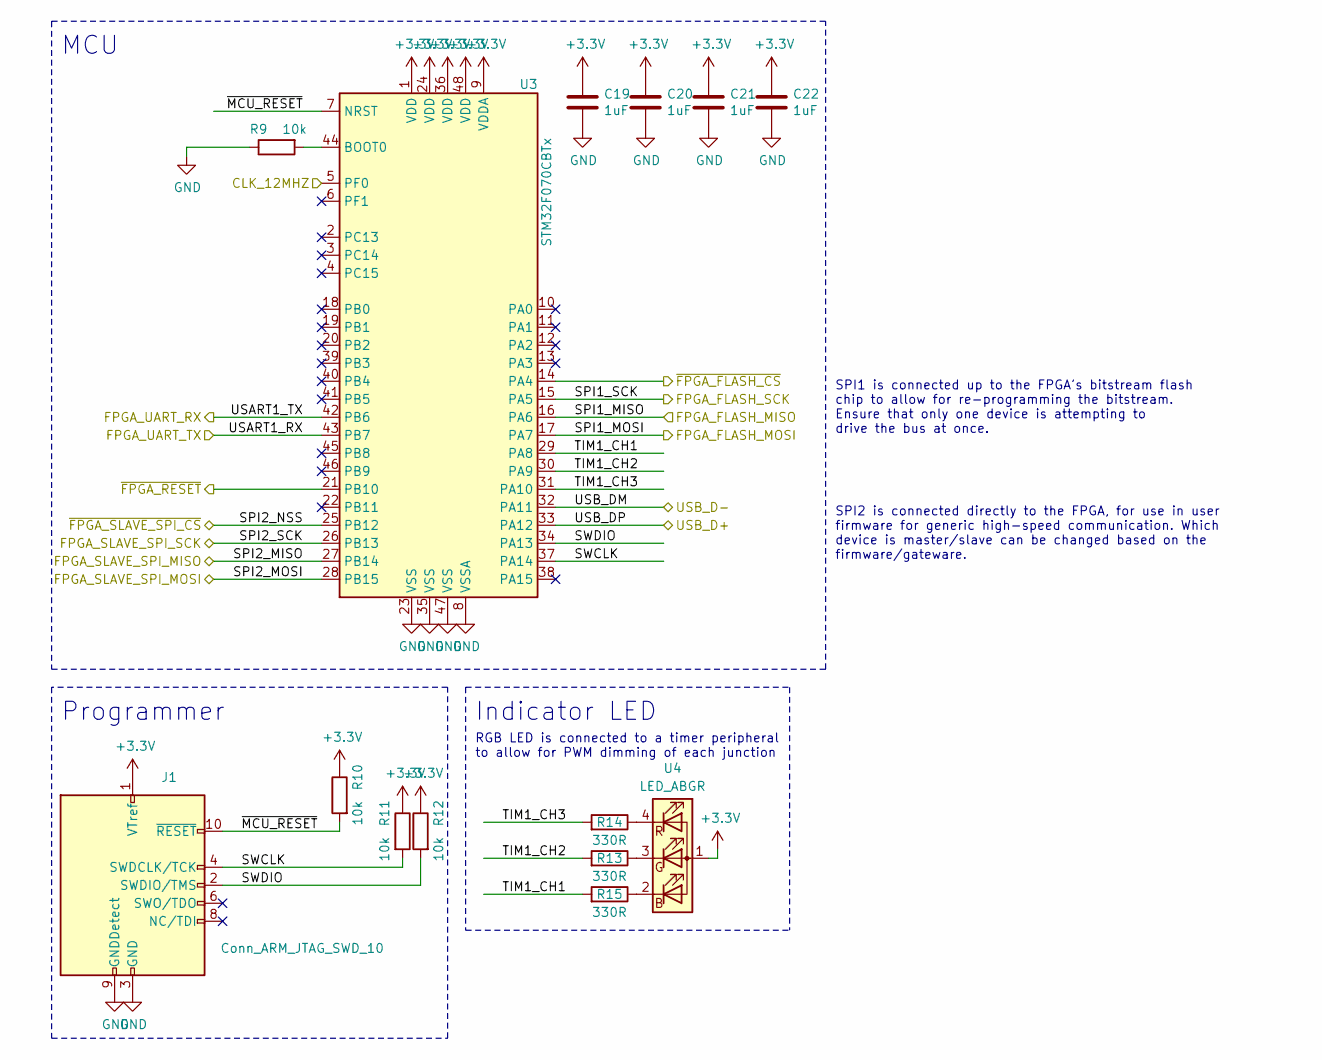
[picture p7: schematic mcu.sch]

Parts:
C19, C20, C21, C22: 1uF; C_0805_2012Metric_Pad1.15x1.40mm_HandSolder; Manufacturer PN CL21B105KOFNNNG; DigiKey PN 1276-6471-1-ND
J1: Conn_ARM_JTAG_SWD_10; Tag-Connect_TC2050-IDC-NL_2x05_P1.27mm_Vertical
R9, R10, R11, R12: 10k; R_0805_2012Metric_Pad1.15x1.40mm_HandSolder; Manufacturer PN RMCF0805FT10K0; DigiKey PN RMCF0805FT10K0TR-ND
R13, R14, R15: 330R; R_0805_2012Metric_Pad1.15x1.40mm_HandSolder; Manufacturer PN RMCF0805FT330R; DigiKey PN RMCF0805FT330RTR-ND
U3: STM32F070CBTx; LQFP-48_7x7mm_P0.5mm; Manufacturer PN STM32F070CBT6; DigiKey PN 497-15099-ND
U4: LED_ABGR; LED_Cree_PLCC4_RGB; Manufacturer PN CLMVC-FKA-CL1D1L71BB7C3C3; DigiKey PN CLMVC-FKA-CL1D1L71BB7C3C3DKR-ND

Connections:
/12MHZ_OSC: U3.5 (PF0); also elsewhere on the board
/FPGA_FLASH_MISO: U3.16 (PA6); also elsewhere on the board
/FPGA_FLASH_MOSI: U3.17 (PA7); also elsewhere on the board
/FPGA_FLASH_SCK: U3.15 (PA5); also elsewhere on the board
/FPGA_SLAVE_SPI_MISO: U3.27 (PB14); also elsewhere on the board
/FPGA_SLAVE_SPI_MOSI: U3.28 (PB15); also elsewhere on the board
/FPGA_SLAVE_SPI_SCK: U3.26 (PB13); also elsewhere on the board
/FPGA_UART_RX: U3.42 (PB6); also elsewhere on the board
/FPGA_UART_TX: U3.43 (PB7); also elsewhere on the board
/MCU_USB_D+: U3.33 (PA12); also elsewhere on the board
/MCU_USB_D-: U3.32 (PA11); also elsewhere on the board
/Sheet5E6E6210/SWCLK: J1.4 (SWDCLK/TCK), R11.2, U3.37 (PA14)
/Sheet5E6E6210/SWDIO: J1.2 (SWDIO/TMS), R12.2, U3.34 (PA13)
/Sheet5E6E6210/TIM1_CH1: R15.2, U3.29 (PA8)
/Sheet5E6E6210/TIM1_CH2: R13.2, U3.30 (PA9)
/Sheet5E6E6210/TIM1_CH3: R14.2, U3.31 (PA10)
/Sheet5E6E6210/~MCU_RESET: J1.10 (~RESET~), R10.2, U3.7 (NRST)
/~FPGA_FLASH_CS: U3.14 (PA4); also elsewhere on the board
/~FPGA_RESET: U3.21 (PB10); also elsewhere on the board
/~FPGA_SLAVE_SPI_CS: U3.25 (PB12); also elsewhere on the board
GND: C19.2, C20.2, C21.2, C22.2, J1.3 (GND), J1.5 (GND), J1.9 (GNDDetect), R9.1, U3.8 (VSSA), U3.23 (VSS), U3.35 (VSS), U3.47 (VSS); also elsewhere on the board
unnamed: R9.2, U3.44 (BOOT0)
unnamed: R13.1, U4.3 (GK)
unnamed: R14.1, U4.4 (RK)
unnamed: R15.1, U4.2 (BK)

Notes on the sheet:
Programmer
Indicator LED
MCU
RGB LED is connected to a timer peripheral to allow for PWM dimming of each junction
SPI1 is connected up to the FPGA's bitstream flash chip to allow for re-programming the bitstream. Ensure that only one device is attempting to drive the bus at once.
SPI2 is connected directly to the FPGA, for use in user firmware for generic high-speed communication. Which device is master/slave can be changed based on the firmware/gateware.

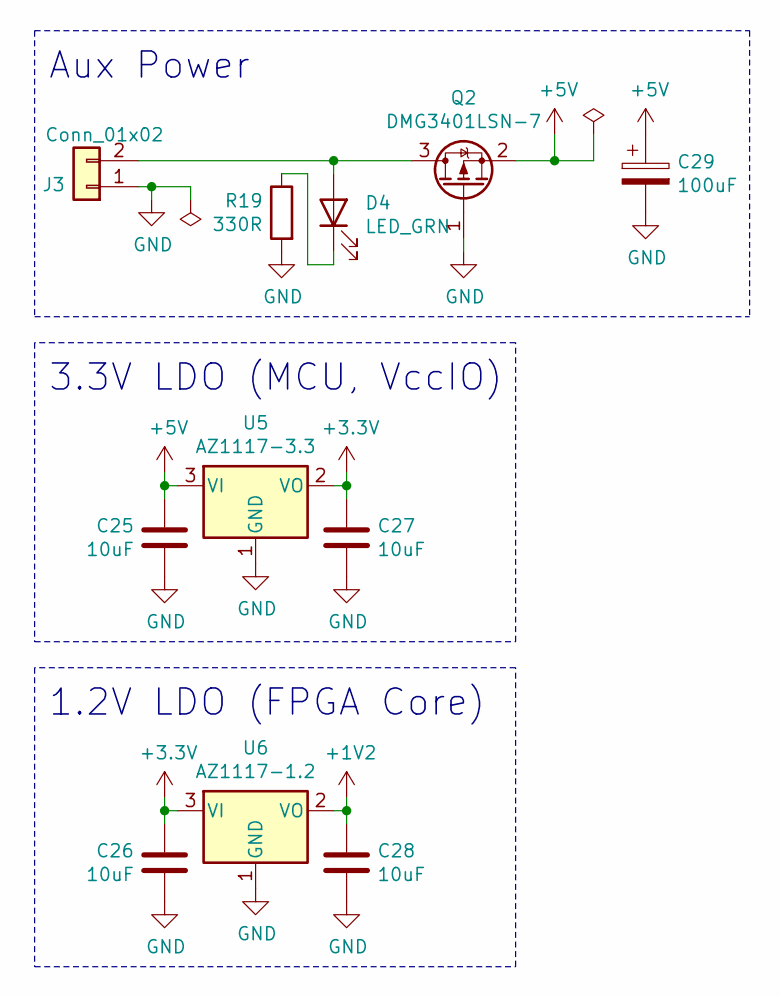
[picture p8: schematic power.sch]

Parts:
C25, C26, C27, C28: 10uF; C_0805_2012Metric_Pad1.15x1.40mm_HandSolder; Manufacturer PN CL21A106KOQNNNG; DigiKey PN 1276-6455-1-ND
C29: 100uF; CP_Elec_6.3x5.8; Manufacturer PN EEE-FT1V101AP; DigiKey PN PCE5016CT-ND
D4: LED_GRN; LED_0805_2012Metric_Pad1.15x1.40mm_HandSolder; Manufacturer PN LTST-C171KGKT; DigiKey PN 160-1426-1-ND
J3: Conn_01x02; Conn_Molex_Mini-Fit-JR_2pos_RA_4.2mm; Manufacturer PN 0039301020; DigiKey PN WM1351-ND
Q2: DMG3401LSN-7; SC-59; Manufacturer PN DMG3401LSN-7; DigiKey PN DMG3401LSN-7DITR-ND
R19: 330R; R_0805_2012Metric_Pad1.15x1.40mm_HandSolder; Manufacturer PN RMCF0805FT330R; DigiKey PN RMCF0805FT330RTR-ND
U5: AZ1117-3.3; SOT-223-3_TabPin2; Manufacturer PN AZ1117CH-3.3TRG1; DigiKey PN AZ1117CH-3.3TRG1DITR-ND
U6: AZ1117-1.2; SOT-223-3_TabPin2; Manufacturer PN AZ1117CH-1.2TRG1; DigiKey PN AZ1117CH-1.2TRG1DICT-ND

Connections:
+1V2: C28.2, U6.2 (VO); also elsewhere on the board
+5V: C25.2, C29.1, Q2.2 (S), U5.3 (VI); also elsewhere on the board
GND: C25.1, C26.1, C27.1, C28.1, C29.2, J3.1, Q2.1 (G), R19.2, U5.1 (GND), U6.1 (GND); also elsewhere on the board
unnamed: D4.1 (K), R19.1
unnamed: D4.2 (A), J3.2, Q2.3 (D)

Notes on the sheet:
Aux Power
3.3V LDO (MCU, VccIO)
1.2V LDO (FPGA Core)

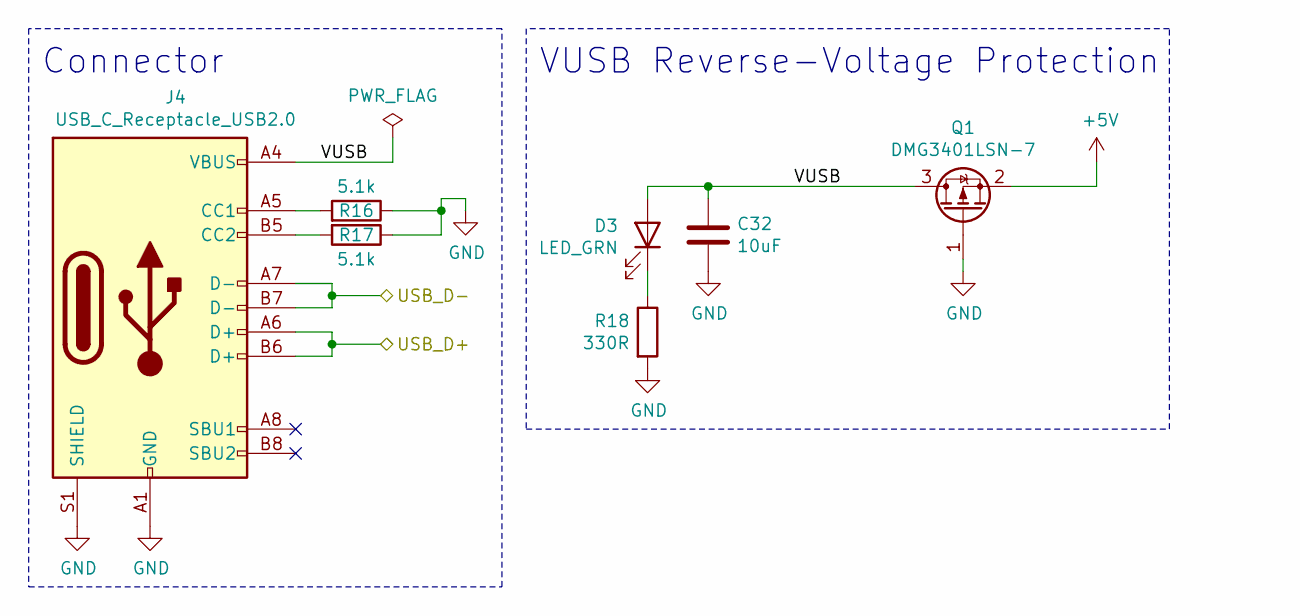
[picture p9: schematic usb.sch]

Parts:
C32: 10uF; C_0805_2012Metric_Pad1.15x1.40mm_HandSolder; Manufacturer PN CL21A106KOQNNNG; DigiKey PN 1276-6455-1-ND
D3: LED_GRN; LED_0805_2012Metric_Pad1.15x1.40mm_HandSolder; Manufacturer PN LTST-C171KGKT; DigiKey PN 160-1426-1-ND
J4: USB_C_Receptacle_USB2.0; Conn_USB_C_Receptacle_GCT_USB4105-GF-A; Manufacturer PN USB4105-GF-A; DigiKey PN 2073-USB4105-GF-ACT-ND
Q1: DMG3401LSN-7; SC-59; Manufacturer PN DMG3401LSN-7; DigiKey PN DMG3401LSN-7DITR-ND
R16, R17: 5.1k; R_0805_2012Metric_Pad1.15x1.40mm_HandSolder; Manufacturer PN RMCF0805FT5K10; DigiKey PN RMCF0805FT5K10TR-ND
R18: 330R; R_0805_2012Metric_Pad1.15x1.40mm_HandSolder; Manufacturer PN RMCF0805FT330R; DigiKey PN RMCF0805FT330RTR-ND

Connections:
+5V: Q1.2 (S); also elsewhere on the board
/MCU_USB_D+: J4.A6 (D+), J4.B6 (D+); also elsewhere on the board
/MCU_USB_D-: J4.A7 (D-), J4.B7 (D-); also elsewhere on the board
/Sheet5E6E65DF/VUSB: C32.1, D3.2 (A), J4.A4 (VBUS), J4.A9 (VBUS), J4.B4 (VBUS), J4.B9 (VBUS), Q1.3 (D)
GND: C32.2, J4.A1 (GND), J4.A12 (GND), J4.B1 (GND), J4.B12 (GND), J4.S1 (SHIELD), Q1.1 (G), R16.1, R17.1, R18.2; also elsewhere on the board
unnamed: D3.1 (K), R18.1
unnamed: J4.A5 (CC1), R16.2
unnamed: J4.B5 (CC2), R17.2

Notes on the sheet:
Connector
VUSB Reverse-Voltage Protection

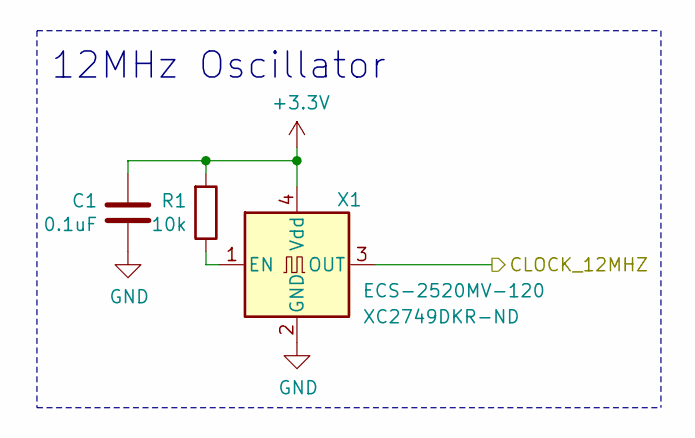
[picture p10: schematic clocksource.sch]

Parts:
C1: 0.1uF; C_0805_2012Metric_Pad1.15x1.40mm_HandSolder; Manufacturer PN CL21B104KBCNNNC; DigiKey PN 1276-1003-1-ND
R1: 10k; R_0805_2012Metric_Pad1.15x1.40mm_HandSolder; Manufacturer PN RMCF0805FT10K0; DigiKey PN RMCF0805FT10K0TR-ND
X1: ECS-2520MV-120; XTAL_OSC_ECS_2520; Manufacturer PN ECS-2520MV-120-BN-TR; DigiKey PN XC2749DKR-ND

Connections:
/12MHZ_OSC: X1.3 (OUT); also elsewhere on the board
GND: C1.1, X1.2 (GND); also elsewhere on the board
unnamed: R1.1, X1.1 (EN)

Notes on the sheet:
12MHz Oscillator

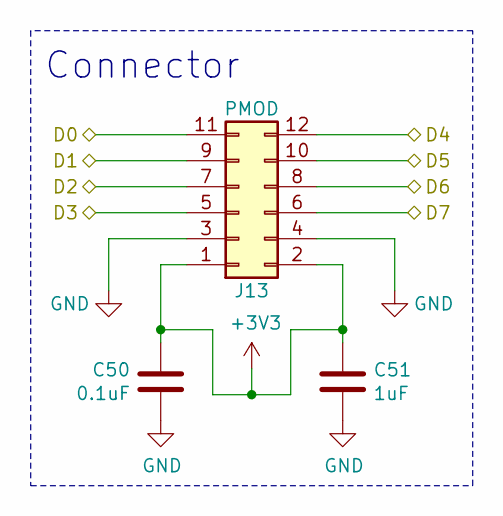
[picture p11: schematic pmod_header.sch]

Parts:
C23: 0.1uF; C_0805_2012Metric_Pad1.15x1.40mm_HandSolder; Manufacturer PN CL21B104KBCNNNC; DigiKey PN 1276-1003-1-ND
C24: 1uF; C_0805_2012Metric_Pad1.15x1.40mm_HandSolder; Manufacturer PN CL21B105KOFNNNG; DigiKey PN 1276-6471-1-ND
J2: PMOD; PinSocket_2x06_P2.54mm_Horizontal; Manufacturer PN PPPC062LJBN-RC; DigiKey PN S5559-ND

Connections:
/Sheet5E6E5EAE/PMOD_A1_D0: J2.11; also elsewhere on the board
/Sheet5E6E5EAE/PMOD_A1_D1: J2.9; also elsewhere on the board
/Sheet5E6E5EAE/PMOD_A1_D2: J2.7; also elsewhere on the board
/Sheet5E6E5EAE/PMOD_A1_D3: J2.5; also elsewhere on the board
/Sheet5E6E5EAE/PMOD_A1_D4: J2.12; also elsewhere on the board
/Sheet5E6E5EAE/PMOD_A1_D5: J2.10; also elsewhere on the board
/Sheet5E6E5EAE/PMOD_A1_D6: J2.8; also elsewhere on the board
/Sheet5E6E5EAE/PMOD_A1_D7: J2.6; also elsewhere on the board
GND: C23.2, C24.2, J2.3, J2.4; also elsewhere on the board

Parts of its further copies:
C34, C36, C38, C40, C42, C44, C46, C48, C50: 0.1uF; C_0805_2012Metric_Pad1.15x1.40mm_HandSolder; Manufacturer PN CL21B104KBCNNNC; DigiKey PN 1276-1003-1-ND
C35, C37, C39, C41, C43, C45, C47, C49, C51: 1uF; C_0805_2012Metric_Pad1.15x1.40mm_HandSolder; Manufacturer PN CL21B105KOFNNNG; DigiKey PN 1276-6471-1-ND
J5, J6, J7, J8, J9, J10, J11, J12, J13: PMOD; PinSocket_2x06_P2.54mm_Horizontal; Manufacturer PN PPPC062LJBN-RC; DigiKey PN S5559-ND

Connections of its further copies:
/Sheet5E6E5EAE/PMOD_A2_D0: J5.11; also elsewhere on the board
/Sheet5E6E5EAE/PMOD_A2_D1: J5.9; also elsewhere on the board
/Sheet5E6E5EAE/PMOD_A2_D2: J5.7; also elsewhere on the board
/Sheet5E6E5EAE/PMOD_A2_D3: J5.5; also elsewhere on the board
/Sheet5E6E5EAE/PMOD_A2_D4: J5.12; also elsewhere on the board
/Sheet5E6E5EAE/PMOD_A2_D5: J5.10; also elsewhere on the board
/Sheet5E6E5EAE/PMOD_A2_D6: J5.8; also elsewhere on the board
/Sheet5E6E5EAE/PMOD_A2_D7: J5.6; also elsewhere on the board
/Sheet5E6E5EAE/PMOD_A3_D0: J6.11; also elsewhere on the board
/Sheet5E6E5EAE/PMOD_A3_D1: J6.9; also elsewhere on the board
/Sheet5E6E5EAE/PMOD_A3_D2: J6.7; also elsewhere on the board
/Sheet5E6E5EAE/PMOD_A3_D3: J6.5; also elsewhere on the board
/Sheet5E6E5EAE/PMOD_A3_D4: J6.12; also elsewhere on the board
/Sheet5E6E5EAE/PMOD_A3_D5: J6.10; also elsewhere on the board
/Sheet5E6E5EAE/PMOD_A3_D6: J6.8; also elsewhere on the board
/Sheet5E6E5EAE/PMOD_A3_D7: J6.6; also elsewhere on the board
/Sheet5E6E5EAE/PMOD_A4_D0: J7.11; also elsewhere on the board
/Sheet5E6E5EAE/PMOD_A4_D1: J7.9; also elsewhere on the board
/Sheet5E6E5EAE/PMOD_A4_D2: J7.7; also elsewhere on the board
/Sheet5E6E5EAE/PMOD_A4_D3: J7.5; also elsewhere on the board
/Sheet5E6E5EAE/PMOD_A4_D4: J7.12; also elsewhere on the board
/Sheet5E6E5EAE/PMOD_A4_D5: J7.10; also elsewhere on the board
/Sheet5E6E5EAE/PMOD_A4_D6: J7.8; also elsewhere on the board
/Sheet5E6E5EAE/PMOD_A4_D7: J7.6; also elsewhere on the board
/Sheet5E6E5EAE/PMOD_B1_D0: J8.11; also elsewhere on the board
/Sheet5E6E5EAE/PMOD_B1_D1: J8.9; also elsewhere on the board
/Sheet5E6E5EAE/PMOD_B1_D2: J8.7; also elsewhere on the board
/Sheet5E6E5EAE/PMOD_B1_D3: J8.5; also elsewhere on the board
/Sheet5E6E5EAE/PMOD_B1_D4: J8.12; also elsewhere on the board
/Sheet5E6E5EAE/PMOD_B1_D5: J8.10; also elsewhere on the board
/Sheet5E6E5EAE/PMOD_B1_D6: J8.8; also elsewhere on the board
/Sheet5E6E5EAE/PMOD_B1_D7: J8.6; also elsewhere on the board
/Sheet5E6E5EAE/PMOD_B2_D0: J9.11; also elsewhere on the board
/Sheet5E6E5EAE/PMOD_B2_D1: J9.9; also elsewhere on the board
/Sheet5E6E5EAE/PMOD_B2_D2: J9.7; also elsewhere on the board
/Sheet5E6E5EAE/PMOD_B2_D3: J9.5; also elsewhere on the board
/Sheet5E6E5EAE/PMOD_B2_D4: J9.12; also elsewhere on the board
/Sheet5E6E5EAE/PMOD_B2_D5: J9.10; also elsewhere on the board
/Sheet5E6E5EAE/PMOD_B2_D6: J9.8; also elsewhere on the board
/Sheet5E6E5EAE/PMOD_B2_D7: J9.6; also elsewhere on the board
/Sheet5E6E5EAE/PMOD_B3_D0: J10.11; also elsewhere on the board
/Sheet5E6E5EAE/PMOD_B3_D1: J10.9; also elsewhere on the board
/Sheet5E6E5EAE/PMOD_B3_D2: J10.7; also elsewhere on the board
/Sheet5E6E5EAE/PMOD_B3_D3: J10.5; also elsewhere on the board
/Sheet5E6E5EAE/PMOD_B3_D4: J10.12; also elsewhere on the board
/Sheet5E6E5EAE/PMOD_B3_D5: J10.10; also elsewhere on the board
/Sheet5E6E5EAE/PMOD_B3_D6: J10.8; also elsewhere on the board
/Sheet5E6E5EAE/PMOD_B3_D7: J10.6; also elsewhere on the board
/Sheet5E6E5EAE/PMOD_B4_D0: J11.11; also elsewhere on the board
/Sheet5E6E5EAE/PMOD_B4_D1: J11.9; also elsewhere on the board
/Sheet5E6E5EAE/PMOD_B4_D2: J11.7; also elsewhere on the board
/Sheet5E6E5EAE/PMOD_B4_D3: J11.5; also elsewhere on the board
/Sheet5E6E5EAE/PMOD_B4_D4: J11.12; also elsewhere on the board
/Sheet5E6E5EAE/PMOD_B4_D5: J11.10; also elsewhere on the board
/Sheet5E6E5EAE/PMOD_B4_D6: J11.8; also elsewhere on the board
/Sheet5E6E5EAE/PMOD_B4_D7: J11.6; also elsewhere on the board
/Sheet5E6E5EAE/PMOD_C1_D0: J13.11; also elsewhere on the board
/Sheet5E6E5EAE/PMOD_C1_D1: J13.9; also elsewhere on the board
/Sheet5E6E5EAE/PMOD_C1_D2: J13.7; also elsewhere on the board
/Sheet5E6E5EAE/PMOD_C1_D3: J13.5; also elsewhere on the board
/Sheet5E6E5EAE/PMOD_C1_D4: J13.12; also elsewhere on the board
/Sheet5E6E5EAE/PMOD_C1_D5: J13.10; also elsewhere on the board
/Sheet5E6E5EAE/PMOD_C1_D6: J13.8; also elsewhere on the board
/Sheet5E6E5EAE/PMOD_C1_D7: J13.6; also elsewhere on the board
/Sheet5E6E5EAE/PMOD_C2_D0: J12.11; also elsewhere on the board
/Sheet5E6E5EAE/PMOD_C2_D1: J12.9; also elsewhere on the board
/Sheet5E6E5EAE/PMOD_C2_D2: J12.7; also elsewhere on the board
/Sheet5E6E5EAE/PMOD_C2_D3: J12.5; also elsewhere on the board
/Sheet5E6E5EAE/PMOD_C2_D4: J12.12; also elsewhere on the board
/Sheet5E6E5EAE/PMOD_C2_D5: J12.10; also elsewhere on the board
/Sheet5E6E5EAE/PMOD_C2_D6: J12.8; also elsewhere on the board
/Sheet5E6E5EAE/PMOD_C2_D7: J12.6; also elsewhere on the board
GND: C34.2, C35.2, C36.2, C37.2, C38.2, C39.2, C40.2, C41.2, C42.2, C43.2, C44.2, C45.2, C46.2, C47.2, C48.2, C49.2, C50.2, C51.2, J5.3, J5.4, J6.3, J6.4, J7.3, J7.4, J8.3, J8.4, J9.3, J9.4, J10.3, J10.4, J11.3, J11.4, J12.3, J12.4, J13.3, J13.4; also elsewhere on the board

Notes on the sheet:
Connector

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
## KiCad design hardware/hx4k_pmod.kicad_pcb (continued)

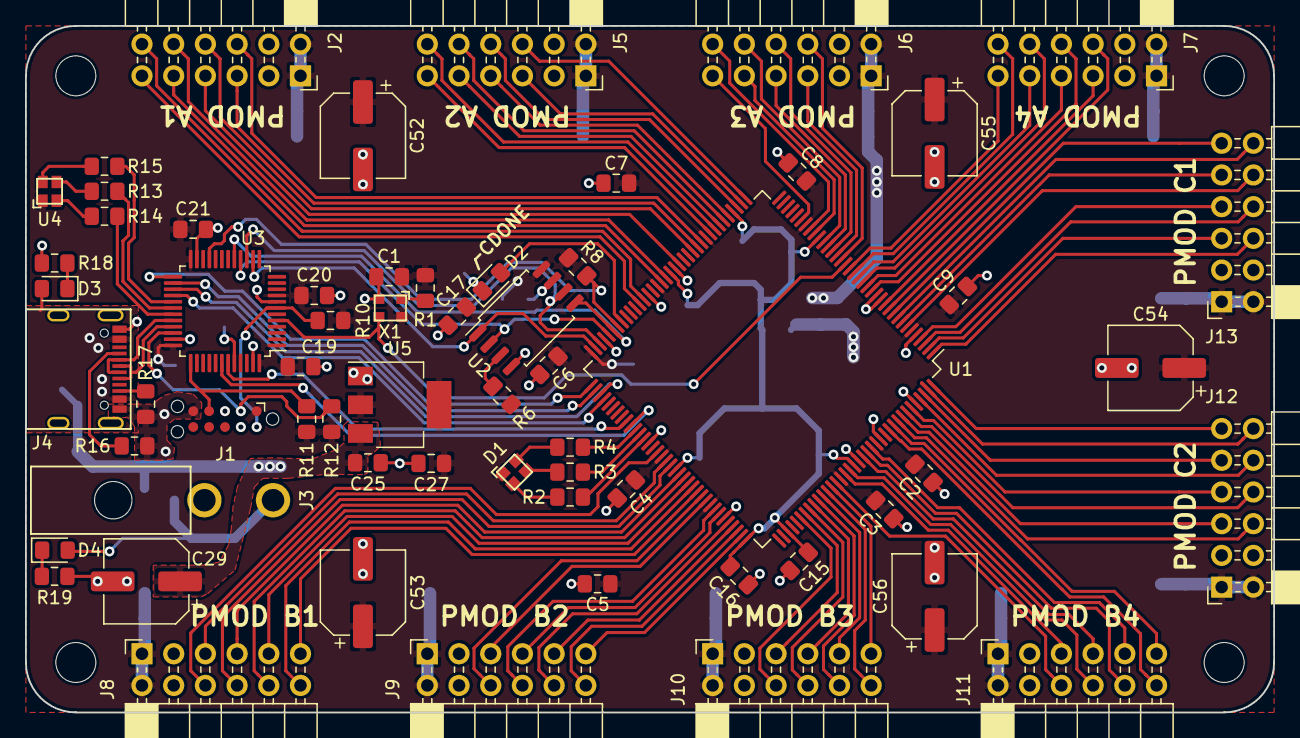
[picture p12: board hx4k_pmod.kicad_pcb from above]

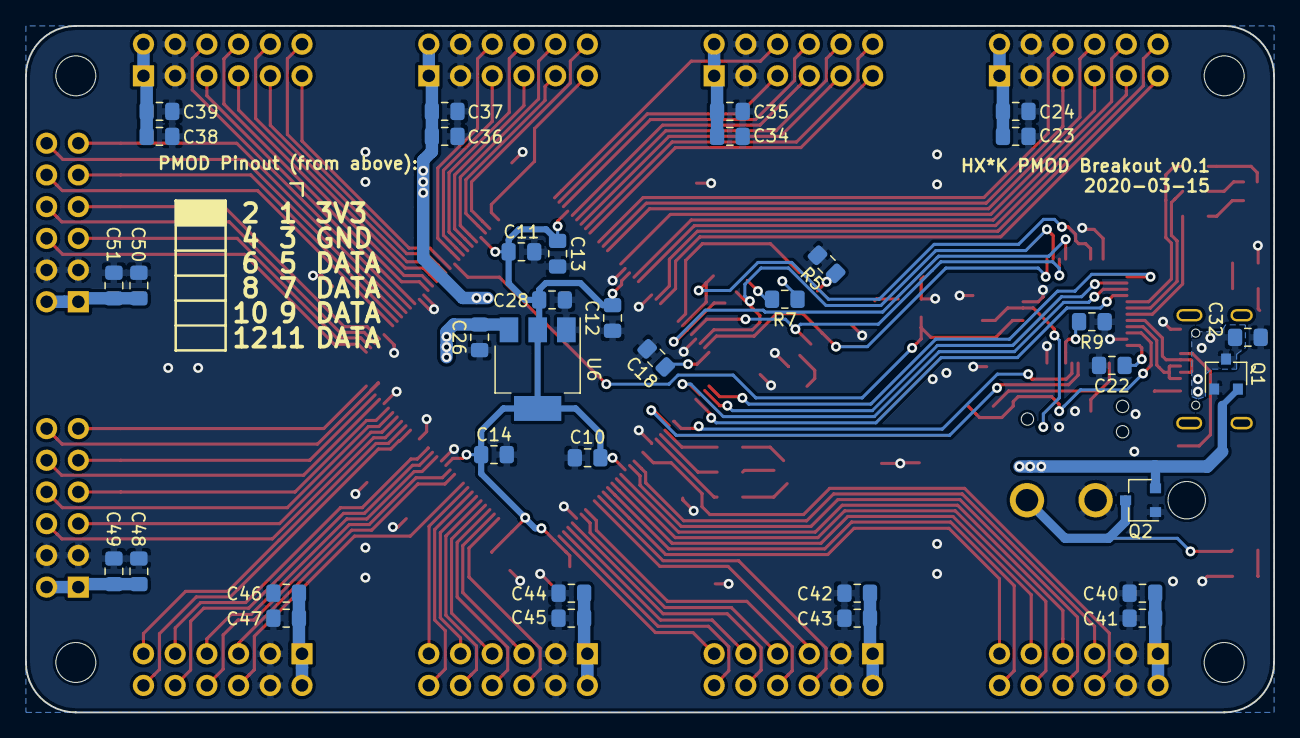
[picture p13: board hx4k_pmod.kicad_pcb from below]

Board: 2 copper layers, 100.0 x 55.0 mm, 103 parts (37 on the bottom side), 125 nets.

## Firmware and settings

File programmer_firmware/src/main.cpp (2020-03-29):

#include <libopencm3/cm3/systick.h>
#include <libopencm3/stm32/flash.h>
#include <libopencm3/stm32/gpio.h>
#include <libopencm3/stm32/i2c.h>
#include <libopencm3/stm32/iwdg.h>
#include <libopencm3/stm32/rcc.h>
#include <libopencm3/stm32/syscfg.h>

#include <config.hpp>

#include <fpga.hpp>
#include <rgb.hpp>
#include <uart.hpp>
#include <usb.hpp>
#include <usb_protocol.hpp>

void clock_setup();
void event_loop();
int main() {
  // Enable watchdog
  iwdg_set_period_ms(50);
  iwdg_reset();
  iwdg_start();

  // Move from default clock source to 48MHz PLL
  clock_setup();

  // Initialize always-on io/peripherals
  FPGA::init();
  UART::init();
  RGB::init();
  UsbProto::init();
  USB::init();

  // Run event loop forever
  while (true) {
    event_loop();
  }
}

void clock_setup() {
  //// Set clock at 48MHz from shared 12MHz oscillator
  // First need to enable the external oscillator, and switch to it
  // as our system clock source
  rcc_osc_on(RCC_HSE);
  rcc_wait_for_osc_ready(RCC_HSE);
  rcc_set_sysclk_source(RCC_HSE);

  // No AHB / APB prescaler, since they can run at 48MHz
  rcc_set_hpre(RCC_CFGR_HPRE_NODIV);
  rcc_set_ppre(RCC_CFGR_PPRE_NODIV);

  // Need to enable flash prefetching for 48MHz operation
  flash_prefetch_enable();
  flash_set_ws(FLASH_ACR_LATENCY_024_048MHZ);

  // PLL config: 12MHz * 4 = 48MHz
  rcc_set_pll_multiplication_factor(RCC_CFGR_PLLMUL_MUL4);
  rcc_set_pll_source(RCC_CFGR_PLLSRC_HSE_CLK);
  rcc_set_pllxtpre(RCC_CFGR_PLLXTPRE_HSE_CLK);

  // Enable the PLL, wait for it to lock and change over to it as
  // the system clock source
  rcc_osc_on(RCC_PLL);
  rcc_wait_for_osc_ready(RCC_PLL);
  rcc_set_sysclk_source(RCC_PLL);

  // These globals are used in opencm3, need to make sure we set them to the
  // correct system clock speed
  rcc_apb1_frequency = 48'000'000;
  rcc_ahb_frequency = 48'000'000;
}

void event_loop() {
  // Poll for new USB events
  USB::poll();

  // Check if we need to flush the UART rx buffer
  if (UART::available() && USB::can_transmit_serial_packet()) {
    uint8_t buf[64];
    unsigned count = UART::receive(buf, sizeof(buf));
    USB::transmit_serial_packet(buf, count);
  }

  // Tickle watchdog
  iwdg_reset();
}

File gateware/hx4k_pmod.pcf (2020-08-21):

# 12 MHz clock
set_io -nowarn CLK_12MHZ     21

# RGB led
set_io -nowarn LED_R        85
set_io -nowarn LED_G        84
set_io -nowarn LED_B        83

# SPI connection to flash chip
set_io -nowarn FLASH_SPI_CS   71
set_io -nowarn FLASH_SPI_SCK  70
set_io -nowarn FLASH_SPI_MISO 68
set_io -nowarn FLASH_SPI_MOSI 67

# SPI connection to microcontroller
set_io -nowarn MCU_SPI_CS   73
set_io -nowarn MCU_SPI_SCK  74
set_io -nowarn MCU_SPI_MISO 75
set_io -nowarn MCU_SPI_MOSI 76

# UART connection to microcontroller
# Note that these names are from the point of view of the MCU.
# The FPGA should TRANSMIT on MCU_RX, and RECEIVE on MCU_TX
set_io -nowarn MCU_UART_RX 81
set_io -nowarn MCU_UART_TX 82

### PMODs


# A1
set_io -nowarn PMOD_A1[0]   61
set_io -nowarn PMOD_A1[1]   56
set_io -nowarn PMOD_A1[2]   52
set_io -nowarn PMOD_A1[3]   48
set_io -nowarn PMOD_A1[4]   60
set_io -nowarn PMOD_A1[5]   55
set_io -nowarn PMOD_A1[6]   49
set_io -nowarn PMOD_A1[7]   47

# A2
set_io -nowarn PMOD_A2[0]   45
set_io -nowarn PMOD_A2[1]   43
set_io -nowarn PMOD_A2[2]   41
set_io -nowarn PMOD_A2[3]   38
set_io -nowarn PMOD_A2[4]   44
set_io -nowarn PMOD_A2[5]   42
set_io -nowarn PMOD_A2[6]   39
set_io -nowarn PMOD_A2[7]   37

# A3
set_io -nowarn PMOD_A3[0]   31
set_io -nowarn PMOD_A3[1]   28
set_io -nowarn PMOD_A3[2]   25
set_io -nowarn PMOD_A3[3]   23
set_io -nowarn PMOD_A3[4]   29
set_io -nowarn PMOD_A3[5]   26
set_io -nowarn PMOD_A3[6]   24
set_io -nowarn PMOD_A3[7]   22

# A4
set_io -nowarn PMOD_A4[0]   20
set_io -nowarn PMOD_A4[1]   18
set_io -nowarn PMOD_A4[2]   16
set_io -nowarn PMOD_A4[3]   12
set_io -nowarn PMOD_A4[4]   19
set_io -nowarn PMOD_A4[5]   17
set_io -nowarn PMOD_A4[6]   15
set_io -nowarn PMOD_A4[7]   11

# B1
set_io -nowarn PMOD_B1[0]   97
set_io -nowarn PMOD_B1[1]   95
set_io -nowarn PMOD_B1[2]   93
set_io -nowarn PMOD_B1[3]   90
set_io -nowarn PMOD_B1[4]   96
set_io -nowarn PMOD_B1[5]   94
set_io -nowarn PMOD_B1[6]   91
set_io -nowarn PMOD_B1[7]   88

# B2
set_io -nowarn PMOD_B2[0]   107
set_io -nowarn PMOD_B2[1]   105
set_io -nowarn PMOD_B2[2]   102
set_io -nowarn PMOD_B2[3]   99
set_io -nowarn PMOD_B2[4]   106
set_io -nowarn PMOD_B2[5]   104
set_io -nowarn PMOD_B2[6]   101
set_io -nowarn PMOD_B2[7]   98

# B3
set_io -nowarn PMOD_B3[0]   121
set_io -nowarn PMOD_B3[1]   119
set_io -nowarn PMOD_B3[2]   117
set_io -nowarn PMOD_B3[3]   115
set_io -nowarn PMOD_B3[4]   120
set_io -nowarn PMOD_B3[5]   118
set_io -nowarn PMOD_B3[6]   116
set_io -nowarn PMOD_B3[7]   114

# B4
set_io -nowarn PMOD_B4[0]   135
set_io -nowarn PMOD_B4[1]   130
set_io -nowarn PMOD_B4[2]   128
set_io -nowarn PMOD_B4[3]   124
set_io -nowarn PMOD_B4[4]   134
set_io -nowarn PMOD_B4[5]   129
set_io -nowarn PMOD_B4[6]   125
set_io -nowarn PMOD_B4[7]   122

# C1
set_io -nowarn PMOD_C1[0]   10
set_io -nowarn PMOD_C1[1]   8
set_io -nowarn PMOD_C1[2]   4
set_io -nowarn PMOD_C1[3]   2
set_io -nowarn PMOD_C1[4]   9
set_io -nowarn PMOD_C1[5]   7
set_io -nowarn PMOD_C1[6]   3
set_io -nowarn PMOD_C1[7]   1

# C2
set_io -nowarn PMOD_C2[0]   144
set_io -nowarn PMOD_C2[1]   142
set_io -nowarn PMOD_C2[2]   139
set_io -nowarn PMOD_C2[3]   137
set_io -nowarn PMOD_C2[4]   143
set_io -nowarn PMOD_C2[5]   141
set_io -nowarn PMOD_C2[6]   138
set_io -nowarn PMOD_C2[7]   136

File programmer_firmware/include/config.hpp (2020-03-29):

#pragma once

#include <libopencm3/cm3/nvic.h>
#include <libopencm3/stm32/gpio.h>
#include <libopencm3/stm32/rcc.h>
#include <libopencm3/stm32/spi.h>
#include <libopencm3/stm32/timer.h>
#include <libopencm3/stm32/usart.h>

// To try and makes this firmware adaptable to other use cases, the IO defines
// for all peripherals have been broken out here for easier meddling.

namespace config {

// Direct FPGA interface
static const rcc_periph_clken fpga_en_rcc = RCC_GPIOB;
static const uint32_t fpga_en_port = GPIOB;
static const uint32_t fpga_en_pin = GPIO10;

// Flash chip IO configuration
static const uint32_t bitstream_flash_spi = SPI1;
static const rcc_periph_clken bitstream_flash_gpio_rcc = RCC_GPIOA;
static const rcc_periph_clken bitstream_flash_spi_rcc = RCC_SPI1;
static const uint32_t bitstream_flash_spi_port = GPIOA;
static const uint16_t bitstream_flash_spi_pins = GPIO5 | GPIO6 | GPIO7;
static const uint8_t bitstream_flash_spi_af = GPIO_AF0;

// Flash chip select
static const rcc_periph_clken bitstream_flash_cs_rcc = RCC_GPIOA;
static const uint32_t bitstream_flash_cs_port = GPIOA;
static const uint16_t bitstream_flash_cs_pins = GPIO4;

// UART (bridged to USB CDC-ACM endpoint)
static const uint32_t fpga_uart = USART1;
static const rcc_periph_clken fpga_uart_gpio_rcc = RCC_GPIOB;
static const rcc_periph_clken fpga_uart_rcc = RCC_USART1;
static const uint8_t fpga_uart_irq = NVIC_USART1_IRQ;
static const uint32_t fpga_uart_port = GPIOB;
static const uint16_t fpga_uart_pins = GPIO6 | GPIO7;
static const uint8_t fpga_uart_af = 0;
static const uint32_t fpga_uart_baudrate = 2'000'000;

// USB vendor / product information
static const uint16_t usb_id_vendor = 0x1209;
static const uint16_t usb_id_product = 0x0001;
static const uint16_t usb_id_bcd_device_revision = 0x0200;
// USB Strings
static const char *usb_string_manufacturer = "Ross Schlaikjer";
static const char *usb_string_product = "FPGA Bitstream Programmer";

// RGB status LEDs
static const rcc_periph_clken rgb_led_gpio_rcc = RCC_GPIOA;
static const uint32_t rgb_led_port = GPIOA;
static const uint16_t rgb_led_pin_r = GPIO10;
static const uint16_t rgb_led_pin_g = GPIO9;
static const uint16_t rgb_led_pin_b = GPIO8;
// Timer for PWM control of LEDs
static const rcc_periph_clken rgb_led_timer_rcc = RCC_TIM1;
static const uint32_t rgb_led_timer = TIM1;
static const uint8_t rgb_led_timer_af = GPIO_AF2;

} // namespace config

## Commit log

2020-03-28 Hardware design
    [clocksource.sch, fpga.sch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]
2020-03-28 RGB, timer, fpga reset init
    [config.hpp, fpga.cpp, rgb.cpp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]
2020-03-28 USB device shows up
2020-03-28 Start fleshing out protocol, add SPI
2020-03-28 Allow manual LED setting
2020-03-28 Getting device by vid/pid/serial works
2020-03-29 Throw away CDC data to prevent it clogging pipes
    [config.hpp, usb.cpp]
2020-03-29 Print error reasons
2020-03-29 Wire up uart pipe
2020-03-29 README and images
    [digikey_bom.csv]
2020-03-29 Elaborate on assembly a bit
2020-04-12 Use condensed format for PMOD wires
2020-08-21 Fix placement error for A2[7]
    [hx4k_pmod.pcf]
